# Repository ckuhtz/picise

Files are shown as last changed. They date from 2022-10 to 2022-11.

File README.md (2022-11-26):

# Picise

Prototype for a time / location accessory for a Raspberry Pi 40-pin GPIO.

## Goals:

- high quality time (including pps) and location source
- low cost but not cheap
- all 3.3VDC to keep things simple
- clearance for Pi52's ICE Tower coolers

Vertical GPIO riser with 
- HAT EEPROM, 
- GNSS, 
- GNSS battery backup, 
- indicators for power and GNSS fix,
- 3.3VDC fan header.

## BOM:

[Digikey](https://www.digikey.com/short/rnq4tnz8)

## Status:

**2022-11-25: rev2 design in progress.**

**2022-11-24: rev1 assembled, working (click on video below). Planning rev2 improvements.**

### PCB:

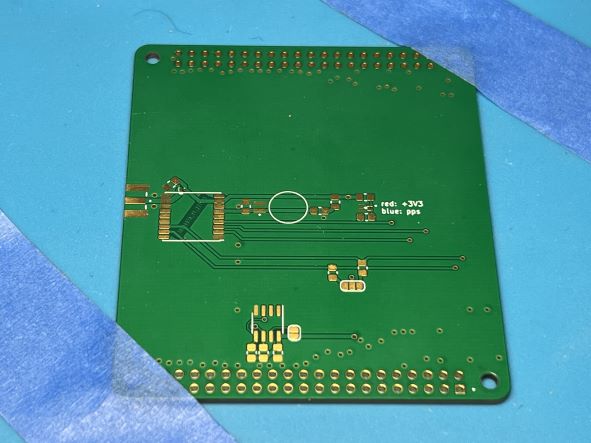
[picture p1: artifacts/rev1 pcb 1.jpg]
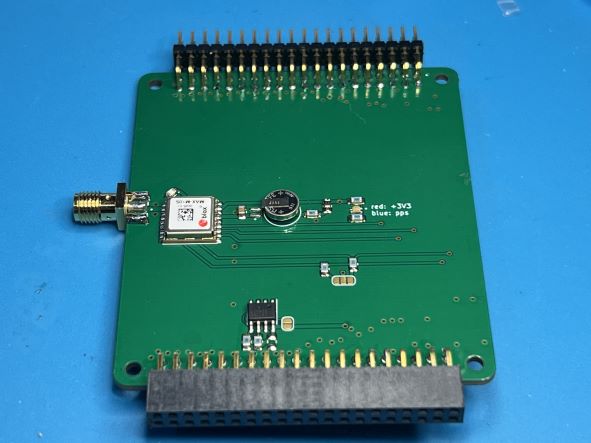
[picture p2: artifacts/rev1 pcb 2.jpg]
<p>

### Video:

working picise module showing 1 per second timing pulse with blue LED (https://www.youtube.com/shorts/lg2OkTD7_zg)

**2022-11-01: rev1 prototype boards received, pending assembly.**

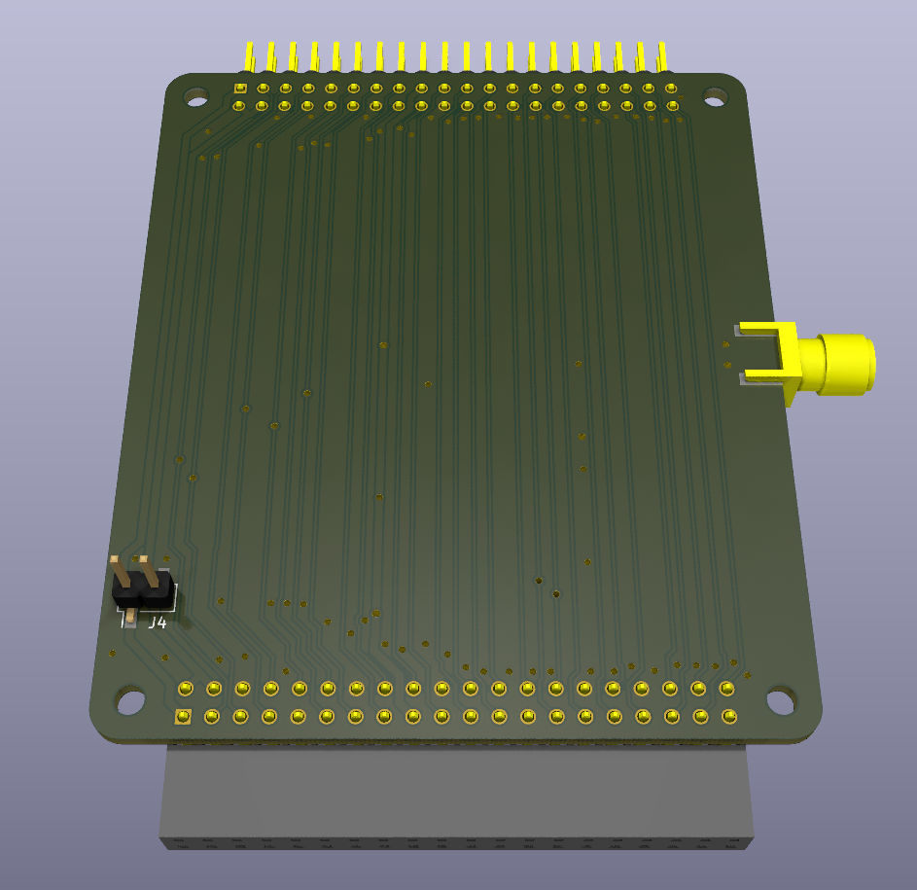
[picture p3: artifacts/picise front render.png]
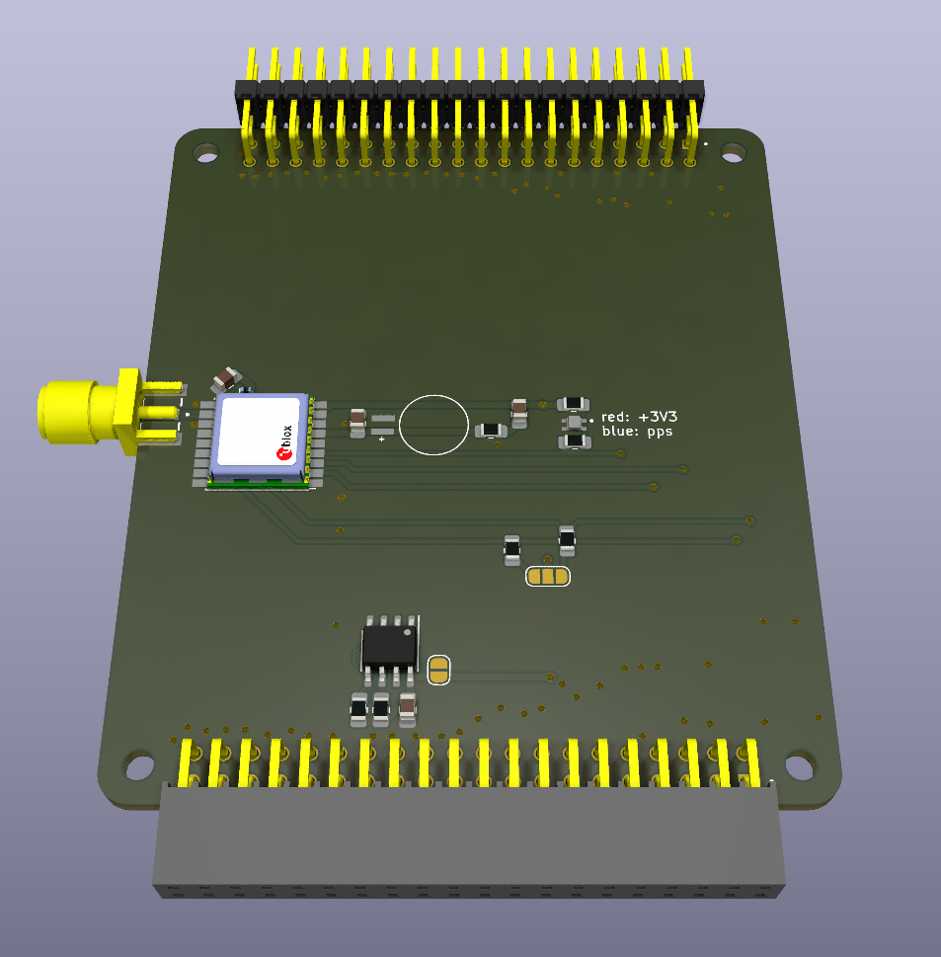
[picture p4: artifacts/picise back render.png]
<p>

Library not published at this time.  Can't remember what has which licensing where I used stuff from vendors.

## License:

CC BY-SA 4.0, see [LICENSE](LICENSE) file.

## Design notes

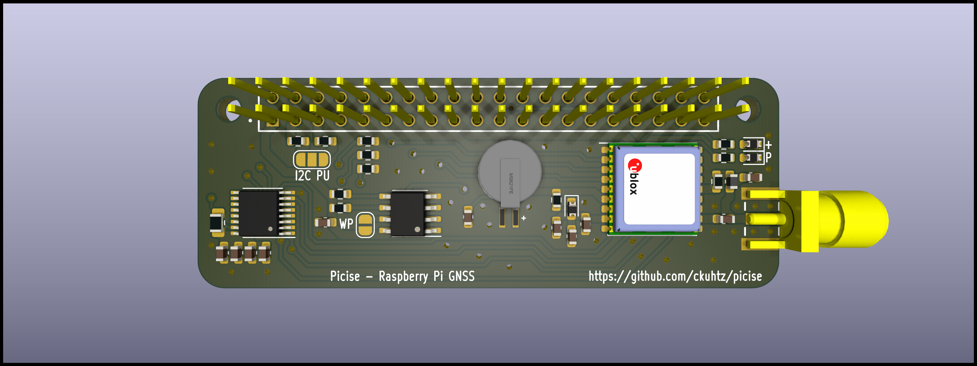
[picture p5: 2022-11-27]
artifacts/picise front render rev2.png

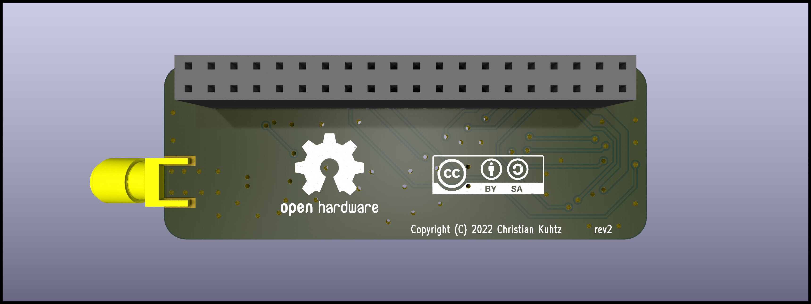
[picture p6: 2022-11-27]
artifacts/picise back render rev2.png

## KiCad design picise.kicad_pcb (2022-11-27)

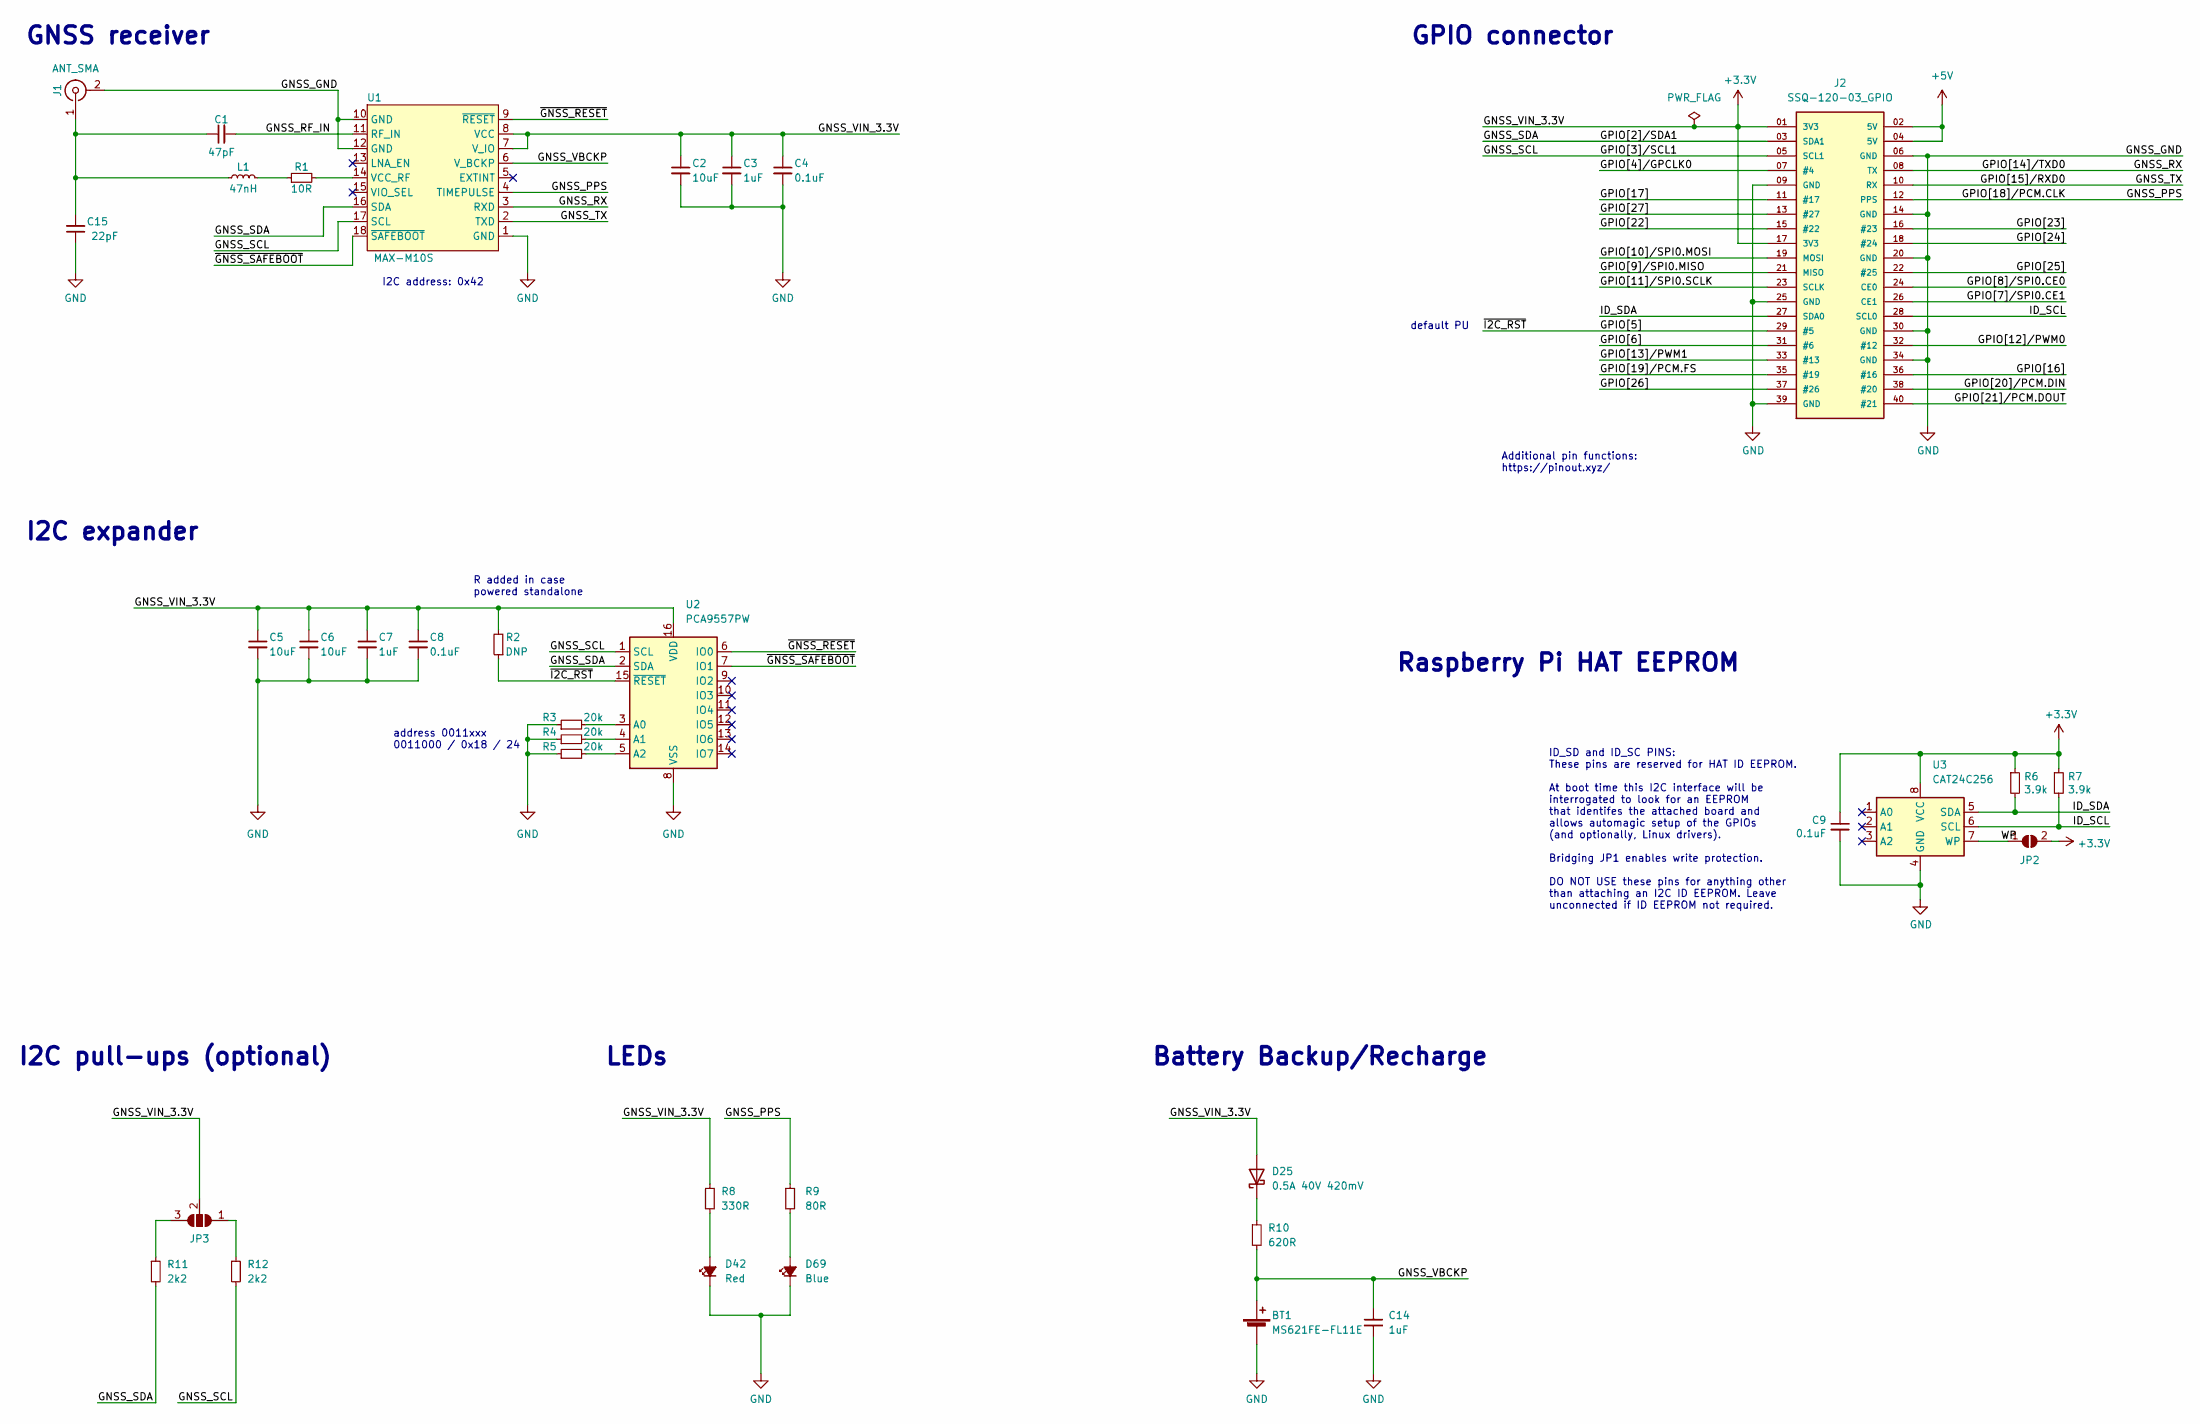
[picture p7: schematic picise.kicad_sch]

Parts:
BT1: MS621FE-FL11E; BAT_MS621FE-FL11E; MPN MS621FE-FL11E; Digikey MS621FE-FL11E
C1: 47pF; C_0603_1608Metric; MPN CL10C470JB8NNNC; JLCPCB C1671
C2, C5, C6: 10uF; C_0603_1608Metric; MPN CL05A106MQ5NUNC; JLCPCB C15525
C3, C7, C14: 1uF; C_0603_1608Metric; MPN CL10A105KB8NNNC; JLCPCB C15849
C4, C8, C9: 0.1uF; C_0603_1608Metric; MPN CC0603KRX7R9BB104; JLCPCB C14663
C15: 22pF; C_0603_1608Metric; MPN CL10C470JB8NNNC; JLCPCB C1671
D25: 0.5A 40V 420mV; D_0603_1608Metric; MPN SD0603S040S0R2; JLCPCB C143772
D42: Red; D_0603_1608Metric; MPN LTST-C191KRKT; JLCPCB C125099
D69: Blue; D_0603_1608Metric; MPN 19-217/BHC-ZL1M2RY/3T; JLCPCB C72041
J1: ANT_SMA; SAMTEC_SMA-J-P-H-ST-EM1; MPN SMA-J-P-H-ST-EM1; Digikey SMA-J-P-H-ST-EM1
J2: SSQ-120-03_GPIO; SAMTEC_SSQ-120-03-G-D_Pi; MPN SSQ-120-03-G-D; Digikey SSQ-120-03-G-D
JP2: ID_WP; SolderJumper-2_P1.3mm_Open_RoundedPad1.0x1.5mm
JP3: SolderJumper_3_Open; SolderJumper-3_P1.3mm_Open_RoundedPad1.0x1.5mm
L1: 47nH; L_0603_1608Metric; MPN LQW18AN47NG00D; JLCPCB C98076
R1: 10R; R_0603_1608Metric; MPN 0603WAF100JT5E; JLCPCB C22859
R2: DNP; R_0805_2012Metric_Pad1.20x1.40mm_HandSolder
R3, R4, R5: 20k; R_0603_1608Metric; MPN 0603WAF2002T5E; JLCPCB C4184
R6, R7: 3.9k; R_0603_1608Metric; MPN 0603WAF3901T5E; JLCPCB C23018
R8: 330R; R_0603_1608Metric; MPN 0603WAF3300T5E; JLCPCB C23138
R9: 80R; R_0603_1608Metric; MPN 0603WAF806JT5E; JLCPCB C23115
R10: 620R; R_0603_1608Metric; MPN 0603WAF6200T5E; JLCPCB C23220
R11, R12: 2k2; R_0603_1608Metric; MPN 0603WAF2201T5E; JLCPCB C4190
U1: MAX-M10S; MPN MAX-M10S-00B
U2: PCA9557PW; TSSOP-16_4.4x5mm_P0.65mm; MPN PCA9557PW; JLCPCB C141380
U3: CAT24C256; SOIC-8_3.9x4.9mm_P1.27mm; MPN CAT24C256WI-GT3; JLCPCB C79987

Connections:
+3V3: C2.1, C3.1, C4.1, C5.1, C6.1, C7.1, C8.1, C9.1, D25.2 (A), J2.01 (3V3), J2.17 (3V3), JP2.2 (B), JP3.2 (C), R2.2, R6.1, R7.1, R8.1, U1.7 (V_IO), U1.8 (VCC), U2.16 (VDD), U3.8 (VCC)
+5V: J2.02 (5V), J2.04 (5V)
/GNSS_PPS: J2.12 (PPS), R9.1, U1.4 (TIMEPULSE)
/GNSS_RF_IN: C1.2, U1.11 (RF_IN)
/GNSS_RX: J2.08 (TX), U1.3 (RXD)
/GNSS_SCL: J2.05 (SCL1), R12.2, U1.17 (SCL), U2.1 (SCL)
/GNSS_SDA: J2.03 (SDA1), R11.2, U1.16 (SDA), U2.2 (SDA)
/GNSS_TX: J2.10 (RX), U1.2 (TXD)
/GNSS_VBCKP: BT1.+, C14.1, R10.2, U1.6 (V_BCKP)
/GPIO[4]/GPCLK0: J2.07 (#4)
/GPIO[5]: J2.29 (#5), R2.1, U2.15 (~RESET)
/GPIO[6]: J2.31 (#6)
/GPIO[7]/SPI0.CE1: J2.26 (CE1)
/GPIO[8]/SPI0.CE0: J2.24 (CE0)
/GPIO[9]/SPI0.MISO: J2.21 (MISO)
/GPIO[10]/SPI0.MOSI: J2.19 (MOSI)
/GPIO[11]/SPI0.SCLK: J2.23 (SCLK)
/GPIO[12]/PWM0: J2.32 (#12)
/GPIO[13]/PWM1: J2.33 (#13)
/GPIO[16]: J2.36 (#16)
/GPIO[17]: J2.11 (#17)
/GPIO[19]/PCM.FS: J2.35 (#19)
/GPIO[20]/PCM.DIN: J2.38 (#20)
/GPIO[21]/PCM.DOUT: J2.40 (#21)
/GPIO[22]: J2.15 (#22)
/GPIO[23]: J2.16 (#23)
/GPIO[24]: J2.18 (#24)
/GPIO[25]: J2.22 (#25)
/GPIO[26]: J2.37 (#26)
/GPIO[27]: J2.13 (#27)
/ID_SCL: J2.28 (SCL0), R7.2, U3.6 (SCL)
/ID_SDA: J2.27 (SDA0), R6.2, U3.5 (SDA)
/WP: JP2.1 (A), U3.7 (WP)
/~GNSS_RESET: U1.9 (~RESET), U2.6 (IO0)
/~GNSS_SAFEBOOT: U1.18 (~SAFEBOOT), U2.7 (IO1)
GND: BT1.-, C2.2, C3.2, C4.2, C5.2, C6.2, C7.2, C8.2, C9.2, C14.2, C15.1, D42.1 (K), D69.1 (K), J1.2, J2.06 (GND), J2.09 (GND), J2.14 (GND), J2.20 (GND), J2.25 (GND), J2.30 (GND), J2.34 (GND), J2.39 (GND), R3.1, R4.1, R5.1, U1.1 (GND), U1.10 (GND), U1.12 (GND), U2.8 (VSS), U3.4 (GND)
unnamed: C1.1, C15.2, J1.1, L1.1
unnamed: D25.1 (K), R10.1
unnamed: D42.2 (A), R8.2
unnamed: D69.2 (A), R9.2
unnamed: JP3.1 (A), R12.1
unnamed: JP3.3 (B), R11.1
unnamed: L1.2, R1.1
unnamed: R1.2, U1.14 (VCC_RF)
unnamed: R3.2, U2.3 (A0)
unnamed: R4.2, U2.4 (A1)
unnamed: R5.2, U2.5 (A2)

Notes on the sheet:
Raspberry Pi HAT EEPROM
Additional pin functions: https://pinout.xyz/
GNSS receiver
Battery Backup/Recharge
ID_SD and ID_SC PINS: These pins are reserved for HAT ID EEPROM. At boot time this I2C interface will be interrogated to look for an EEPROM that identifes the attached board and allows automagic setup of the GPIOs (and optionally, Linux drivers). Bridging JP1 enables write protection. DO NOT USE th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
R added in case powered standalone
I2C expander
I2C address: 0x42
address 0011xxx 0011000 / 0x18 / 24
default PU
GPIO connector
LEDs
I2C pull-ups (optional)

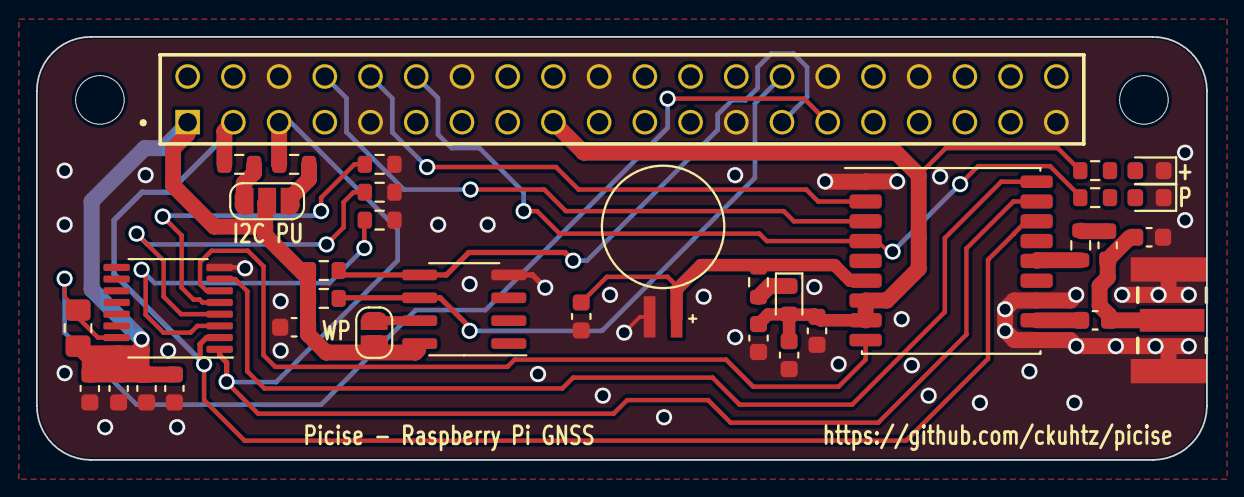
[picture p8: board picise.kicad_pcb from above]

Board: 2 copper layers, 65.0 x 23.5 mm, 37 parts (0 on the bottom side), 27 nets.

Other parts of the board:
MH1, MH2: MountingHole_2.7mm_M2.5

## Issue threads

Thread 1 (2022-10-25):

antenna bias

ckuhtz, 2022-10-25:
check whether antenna bias is working for active antenna. no antenna sup right now, just power.

ckuhtz, 2022-11-24:
busted, passive antenna only.

will be addressed in rev2.

Closed 2022-11-24.

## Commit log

2022-10-31 Update README.md
    Added Digikey BOM
2022-10-31 added BOM
    [picise.csv, picise.kicad_sch]
2022-10-31 BOM tweak
    3-pin to account for left pin 1
    [picise.csv, picise.kicad_sch]
2022-10-31 updated digikey bom link
2022-11-24 rev2 prep
    [picise.kicad_pcb, picise.kicad_sch]
2022-11-24 pcb pics
2022-11-25 rev2 board prep
    [picise.kicad_pcb, picise.kicad_sch]
2022-11-26 rev2 draft routed
    [picise.kicad_pcb, picise.kicad_sch]
2022-11-26 rev2 artifacts
    [picise.kicad_pcb]
2022-11-27 more rev2 work
    [picise.kicad_pcb]
2022-11-27 updated renders
    [picise.kicad_pcb]
2022-11-27 updated origin
    [picise.kicad_pcb]
2022-11-27 fab outputs
    [picise.csv, picise.kicad_pcb]

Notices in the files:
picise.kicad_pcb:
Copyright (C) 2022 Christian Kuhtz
